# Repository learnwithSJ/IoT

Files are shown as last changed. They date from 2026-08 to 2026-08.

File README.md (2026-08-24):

# Smart AI Plug

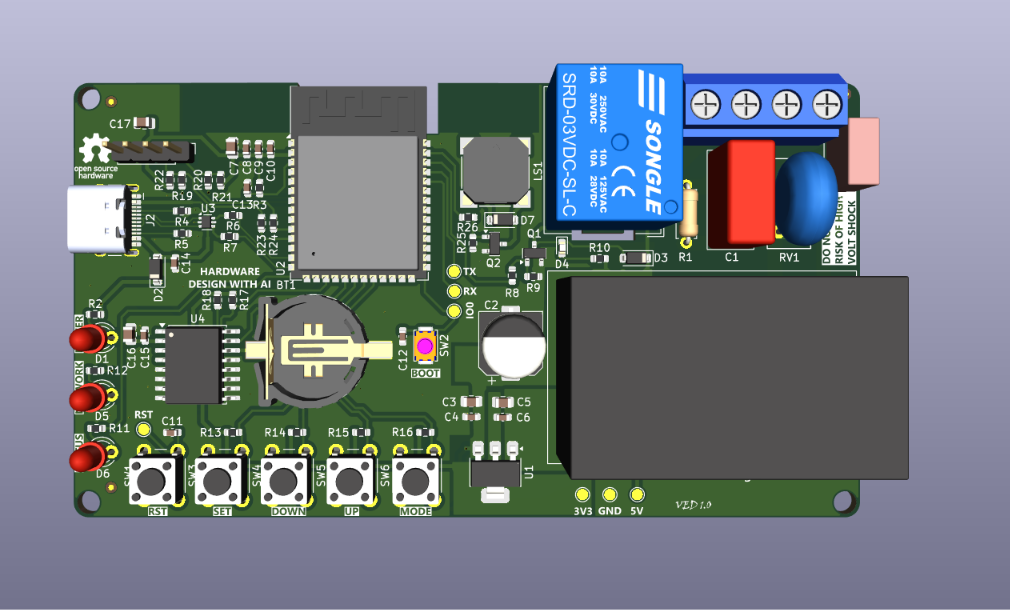
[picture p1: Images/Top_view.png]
Top-img


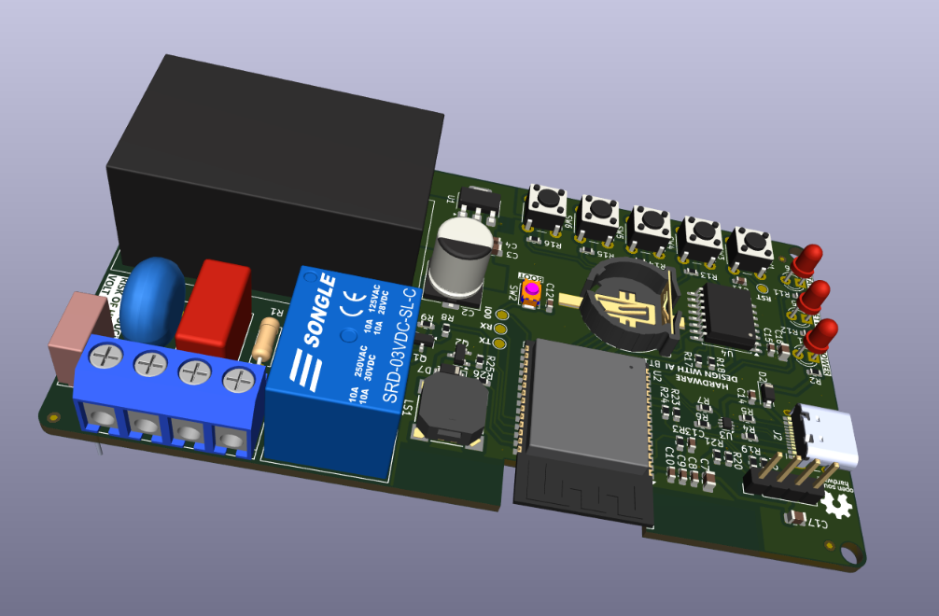
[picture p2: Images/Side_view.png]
Side-img


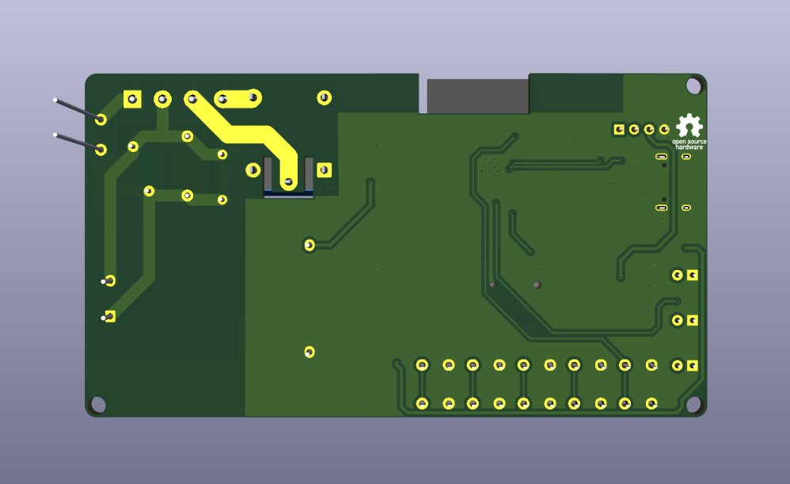
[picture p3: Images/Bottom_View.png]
Bot-img


An ESP32-S3 based IoT smart plug designed for remote and scheduled control of electrical appliances.

> **Project Status:** PCB Design Completed — Hardware Assembly and Testing Not Yet Performed.

## Overview

Smart AI Plug is a smart plug concept designed around the ESP32-S3 microcontroller. The system is intended to provide wireless appliance control along with scheduled operation.

The complete circuit and PCB were designed using **KiCad**.

## Features

* ESP32-S3 based design
* Single-channel relay control (SPDT)
* Wi-Fi and Bluetooth connectivity
* Relay-based appliance switching
* RTC-based scheduled operation
* USB-C interface
* Onboard RTC with battery backup (DS3231M + CH291-1220LF)
* Status LEDs - Network, Error, General indication
* Buzzer feedback (MLT-8530)
* 4x tactile switches for local control
* AC-DC power supply section
* PCB protection circuitry
* Compact PCB design

## 🏗️ System Architecture

```
220V AC Input
     │
     ▼
[F1 Fuse 500mA] ──→ [MOV RV1 Surge Protection]
     │
     ▼
[HLK-5M05] ──→ 5V DC
     │
     ├──→ [Relay K1 SPDT] ──→ Load Output (Screw Terminal J2)
     │
     └──→ [AMS1117-3.3] ──→ 3.3V DC
               │
               ├──→ [ESP32-S3-WROOM-1] ←→ WiFi / BLE
               ├──→ [DS3231M RTC] (I2C)
               ├──→ [Status LEDs]
               ├──→ [Buzzer MLT-8530]
               ├──→ [Tactile Switches x4]
               └──→ [USB-C] ──→ Firmware Flash / Serial Debug
```

---

## 🔧 Hardware Specifications

| Parameter | Details |
|---|---|
| Microcontroller | ESP32-S3-WROOM-1 |
| Input Voltage | 220V AC |
| Operating Voltage | 5V DC / 3.3V DC |
| Power Supply Module | HLK-5M05 (220VAC → 5VDC) |
| LDO Regulator | AMS1117-3.3 |
| Relay | SPDT — 1 Channel |
| RTC | DS3231M (I2C) |
| RTC Battery | CH291-1220LF (Coin Cell) |
| USB Connector | USB-C (USB 2.0) |
| ESD Protection | USBLC6-2P6 |
| Surge Protection | MOV 10D561K |
| Fuse | 500mA / 250V |
| Status LEDs | Red, Blue, Green |
| Buzzer | MLT-8530 |
| Switches | 4x Tactile + 1x Boot + 1x Reset |
| PCB Tool | KiCad 9.0.1 |
| Board Revision | Rev-v0.1.0A |

---

## PCB Design

The schematic and PCB layout were designed using **KiCad**.

## Repository Structure

```text
KiCad/          → KiCad schematic, PCB and project files
Documentation/  → Design documents and diagrams
Images/         → Project images
BOM/            → Bill of Materials
Firmware/       → Firmware documentation
```

## Project Status

The schematic and PCB layout have been completed in KiCad.

The current version is a **design/prototype-stage project**. Physical PCB fabrication, assembly, firmware deployment, and hardware testing have not yet been completed.

## Future Improvements

* Fabricate and assemble the PCB
* Develop and test ESP32-S3 firmware
* Add cloud-based appliance control
* Integrate voice assistant support
* Perform electrical safety and functional testing
* Optimize PCB size and power consumption

## 🏭 Manufacturing

Fabrication files are located in `Hardware/3-Manufacturing-Files/` and include:

- **Gerber files** - for PCB fabrication
- **BOM (Bill of Materials)** - component list with values and part numbers
- **CPL (Component Placement List)** - for SMT assembly

## Designed By

**Shubhank**

## Acknowledgements

Special thanks to **Ampnics** for creating and sharing the original Zeen AI Plug project and providing the YouTube tutorial and open-source resources that helped me understand and recreate this project.

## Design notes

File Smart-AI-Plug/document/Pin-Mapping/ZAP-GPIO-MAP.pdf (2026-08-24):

Zeen-AI-Plug | GPIO Mapping
Device | GPIO | PIN | Type | Comment
3.3V | -- | 2 | PWR
GND | -- | 1/40 | PWR
VBUS | -- | -- | PWR
USB_D+ | IO20 | 14 | PROGRAM/DEBUG
USB_D- | IO19 | 13 | PROGRAM/DEBUG
SW1 | EN | 3 | IN
SW2 | IO0 | 27 | IN
SW3 | IO11 | 19 | IN
SW4 | IO12 | 20 | IN
SW5 | IO13 | 21 | IN
SW6 | IO14 | 22 | IN
RTC_sda | IO8 | 12 | COMM
RTC_scl | IO9 | 17 | COMM
DIS_sda | IO8 | 12 | COMM/OP
DIS_scl | IO9 | 17 | COMM/OP
OPT_dis_sda | IO17 | 10 | COMM/OP
OPT_dis_scl | IO18 | 11 | CPMM/OP
Relay | IO2 | 38 | OP
Network-LED | IO4 | 4 | OP
Status-LED | IO3 | 15 | OP
Buzzer | IO1 | 39 | OP

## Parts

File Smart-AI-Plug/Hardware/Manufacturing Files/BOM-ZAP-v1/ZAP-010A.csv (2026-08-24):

Reference | Qty | Value | DNP | Exclude from BOM | Exclude from Board | Footprint | Datasheet
BT1 | 1 | CH291-1220LF |  |  |  | CH291-1220LF:BAT_CH291-1220LF
C1 | 1 | 0.1uF |  |  |  | Capacitor_THT:C_Rect_L13.0mm_W6.0mm_P10.00mm_FKS3_FKP3_MKS4 | ~
C2 | 1 | 220uF |  |  |  | Capacitor_SMD:CP_Elec_8x10 | ~
C3,C5,C7 | 3 | 10uF |  |  |  | Capacitor_SMD:C_0805_2012Metric | ~
C4,C6,C8,C9,C10,C11,C12,C13,C14,C15 | 10 | 0.1uF |  |  |  | Capacitor_SMD:C_0603_1608Metric | ~
C16 | 1 | 2.2uF |  |  |  | Capacitor_SMD:C_0805_2012Metric | ~
C17 | 1 | 0.1uF |  |  |  | Capacitor_SMD:C_0805_2012Metric | ~
D1,D5,D6 | 3 | RED |  |  |  | LED_THT:LED_D3.0mm | ~
D2 | 1 | MBR0520 |  |  |  | Diode_SMD:D_SOD-123 | http://www.mccsemi.com/up_pdf/MBR0520~MBR0580(SOD123).pdf
D3,D7 | 2 | 1N4148W |  |  |  | Diode_SMD:D_SOD-123 | https://www.vishay.com/docs/85748/1n4148w.pdf
D4 | 1 | RED |  |  |  | LED_SMD:LED_0603_1608Metric | ~
F1 | 1 | 500mA 250V |  |  |  | Fuse:Fuse_Littelfuse_395Series | ~
FID1,FID2,FID3 | 3 | Fiducial |  | Excluded from BOM |  | Fiducial:Fiducial_0.75mm_Mask1.5mm | ~
J1 | 1 | Screw_Terminal_01x04 |  |  |  | TerminalBlock:TerminalBlock_bornier-4_P5.08mm | ~
J2 | 1 | USB_C_Receptacle_USB2.0_16P |  |  |  | Connector_USB:USB_C_Receptacle_HCTL_HC-TYPE-C-16P-01A | https://www.usb.org/sites/default/files/documents/usb_type-c.zip
J3 | 1 | Conn_01x04_Pin |  |  |  | Connector_PinHeader_2.54mm:PinHeader_1x04_P2.54mm_Vertical | ~
K1 | 1 | Relay_SPDT |  |  |  | Relay_THT:Relay_SPDT_Hongfa_HF3F-L-xx-1ZL1T | ~
LS1 | 1 | MLT-8530 |  |  |  | ul_MLT-8530:MLT-8530_JHE
PS1 | 1 | HLK-5M05 |  |  |  | Converter_ACDC:Converter_ACDC_Hi-Link_HLK-5Mxx | http://h.hlktech.com/download/ACDC%E7%94%B5%E6%BA%90%E6%A8%A1%E5%9D%975W%E7%B3%BB%E5%88%97/1/%E6%B5%B7%E5%87%8C%E7%A7%915W%E7%B3%BB%E5%88%97%E7%94%B5%E6%BA%90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
Q1,Q2 | 2 | AO3400A |  |  |  | Package_TO_SOT_SMD:SOT-23 | http://www.aosmd.com/pdfs/datasheet/AO3400A.pdf
R1 | 1 | 1M |  |  |  | Resistor_THT:R_Axial_DIN0207_L6.3mm_D2.5mm_P7.62mm_Horizontal | ~
R2 | 1 | 4K7 |  |  |  | Resistor_SMD:R_0603_1608Metric | ~
R3,R9,R13,R14,R15,R16,R17,R18,R21,R22,R25 | 11 | 10K |  |  |  | Resistor_SMD:R_0603_1608Metric | ~
R4,R5 | 2 | 5K1 |  |  |  | Resistor_SMD:R_0603_1608Metric | ~
R6,R7,R19,R20,R23,R24 | 6 | 0R |  |  |  | Resistor_SMD:R_0603_1608Metric | ~
R8,R10,R11,R12,R26 | 5 | 1K |  |  |  | Resistor_SMD:R_0603_1608Metric | ~
RV1 | 1 | 10D56K |  |  |  | Varistor:RV_Disc_D12mm_W5.8mm_P7.5mm | ~
SW1,SW3,SW4,SW5,SW6 | 5 | SW_Push |  |  |  | Button_Switch_THT:SW_PUSH_6mm | ~
SW2 | 1 | SW_Push |  |  |  | Button_Switch_SMD:SW_Push_SPST_NO_Alps_SKRK | ~
TP1 | 1 | TXD0 |  |  |  | TestPoint:TestPoint_Pad_D1.5mm | ~
TP2 | 1 | RXD0 |  |  |  | TestPoint:TestPoint_Pad_D1.5mm | ~
TP3 | 1 | 3V3 |  |  |  | TestPoint:TestPoint_Pad_D1.5mm | ~
TP4 | 1 | 5V |  |  |  | TestPoint:TestPoint_Pad_D1.5mm | ~
TP5 | 1 | EN |  |  |  | TestPoint:TestPoint_Pad_D1.5mm | ~
TP6 | 1 | BOOT |  |  |  | TestPoint:TestPoint_Pad_D1.5mm | ~
TP7 | 1 | GND |  |  |  | TestPoint:TestPoint_Pad_D1.5mm | ~
U1 | 1 | AMS1117-3.3 |  |  |  | Package_TO_SOT_SMD:SOT-223-3_TabPin2 | http://www.advanced-monolithic.com/pdf/ds1117.pdf
U2 | 1 | ESP32-S3-WROOM-1 |  |  |  | RF_Module:ESP32-S3-WROOM-1 | https://www.espressif.com/sites/default/files/documentation/esp32-s3-wroom-1_wroom-1u_datasheet_en.pdf
U3 | 1 | USBLC6-2P6 |  |  |  | Package_TO_SOT_SMD:SOT-666 | https://www.st.com/resource/en/datasheet/usblc6-2.pdf
U4 | 1 | DS3231M |  |  |  | Package_SO:SOIC-16W_7.5x10.3mm_P1.27mm | http://datasheets.maximintegrated.com/en/ds/DS3231.pdf

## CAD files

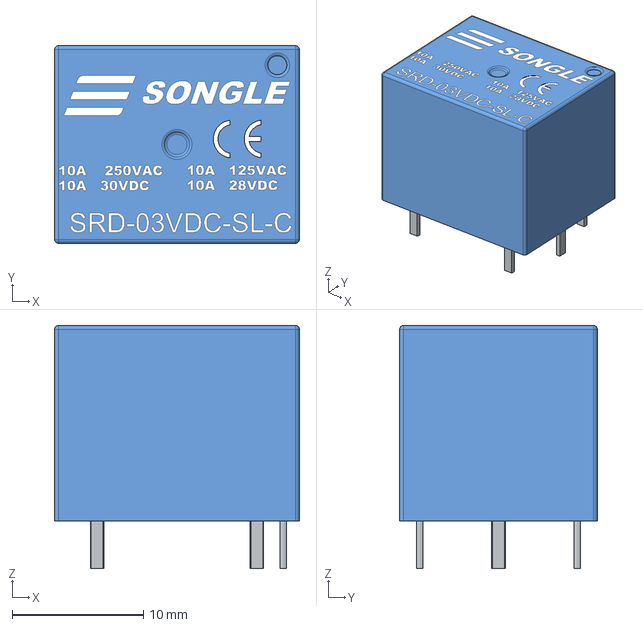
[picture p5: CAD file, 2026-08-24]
Smart-AI-Plug/Hardware/External-3D-Modules/Relay - SRD-03VDC-SL-C.stp
18.7 x 15.1 x 18.6 mm

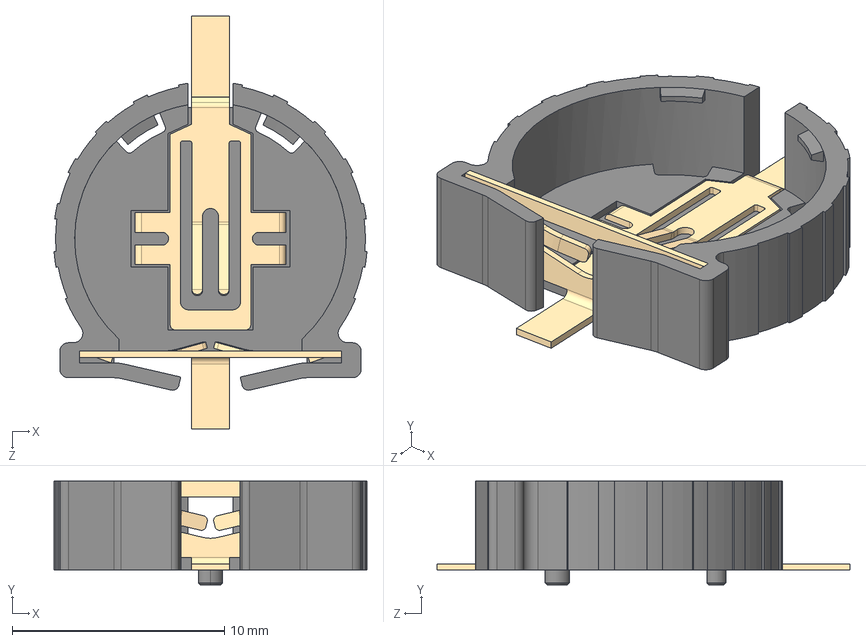
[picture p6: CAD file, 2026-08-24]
Smart-AI-Plug/Hardware/External-libraries/CH291-1220LF/CH291-1220LF.step
14.7 x 4.90 x 19.4 mm

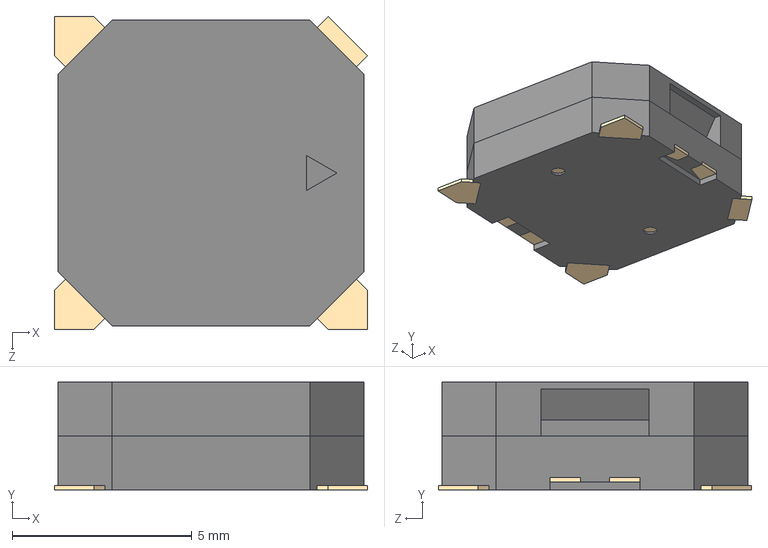
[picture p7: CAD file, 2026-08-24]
Smart-AI-Plug/Hardware/External-3D-Modules/MLT-8530--3DModel-STEP-269445.STEP
8.70 x 3.00 x 8.70 mm

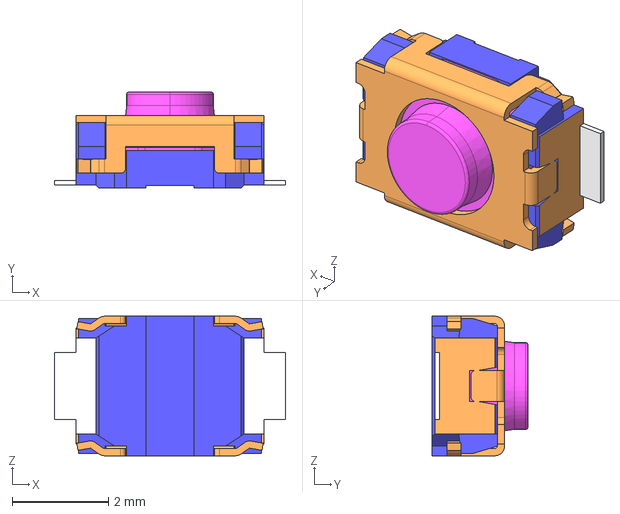
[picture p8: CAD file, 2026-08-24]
Smart-AI-Plug/Hardware/External-3D-Modules/skrkaee010.stp
4.80 x 2.00 x 2.90 mm

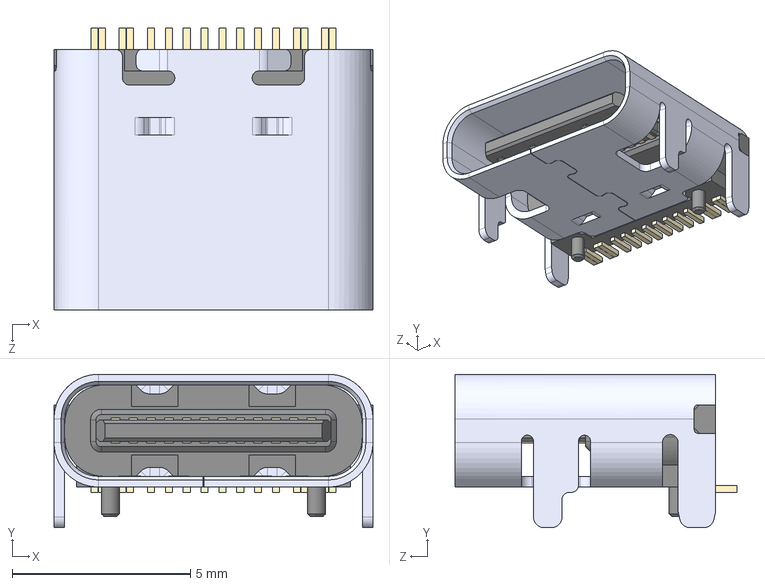
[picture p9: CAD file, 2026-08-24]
Smart-AI-Plug/Hardware/External-3D-Modules/TYPE-C-31-M-12--3DModel-STEP-56544.STEP
8.94 x 4.30 x 7.90 mm

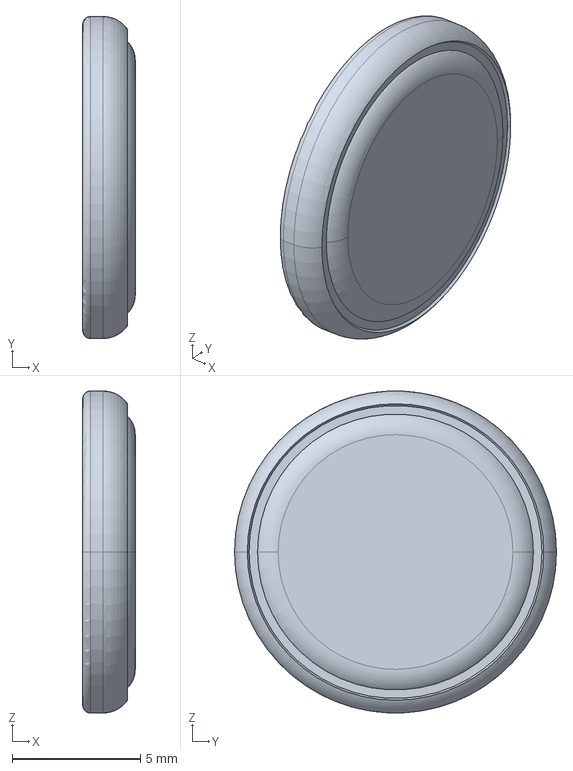
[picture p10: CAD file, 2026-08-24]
Smart-AI-Plug/Hardware/External-3D-Modules/k_cr1220_lithium-cell.stp
2.05 x 12.6 x 12.5 mm

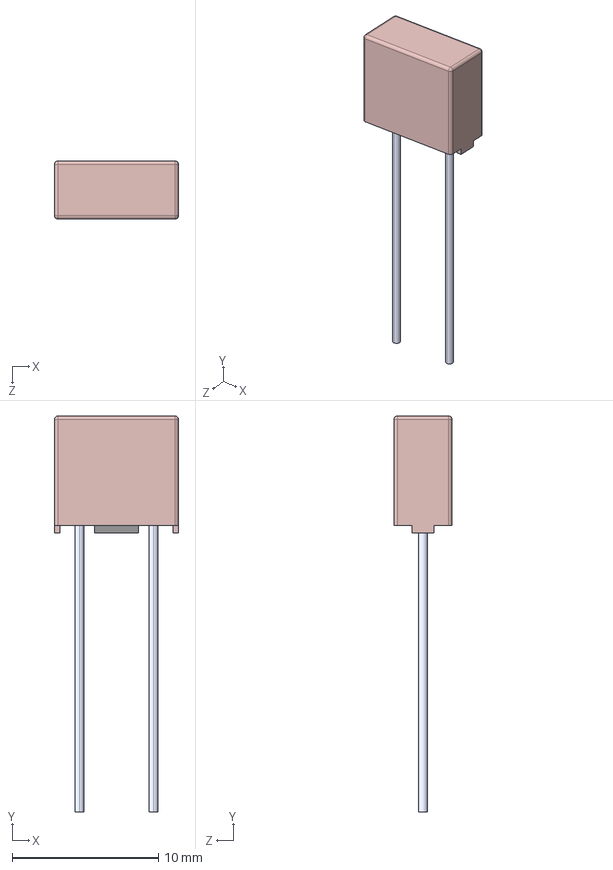
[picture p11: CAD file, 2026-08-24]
Smart-AI-Plug/Hardware/External-3D-Modules/39208000000.STEP
8.50 x 27.1 x 4.00 mm

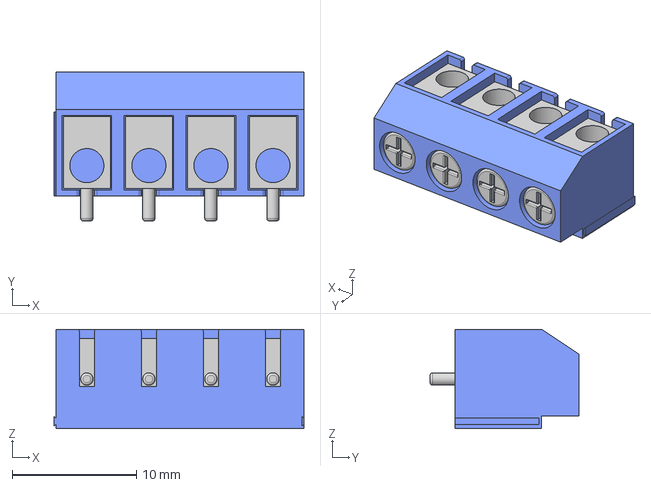
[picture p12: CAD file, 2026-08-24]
Smart-AI-Plug/Hardware/External-3D-Modules/Screw Terminal Block 5mm Blue 4-way.step
20.1 x 12.0 x 8.00 mm

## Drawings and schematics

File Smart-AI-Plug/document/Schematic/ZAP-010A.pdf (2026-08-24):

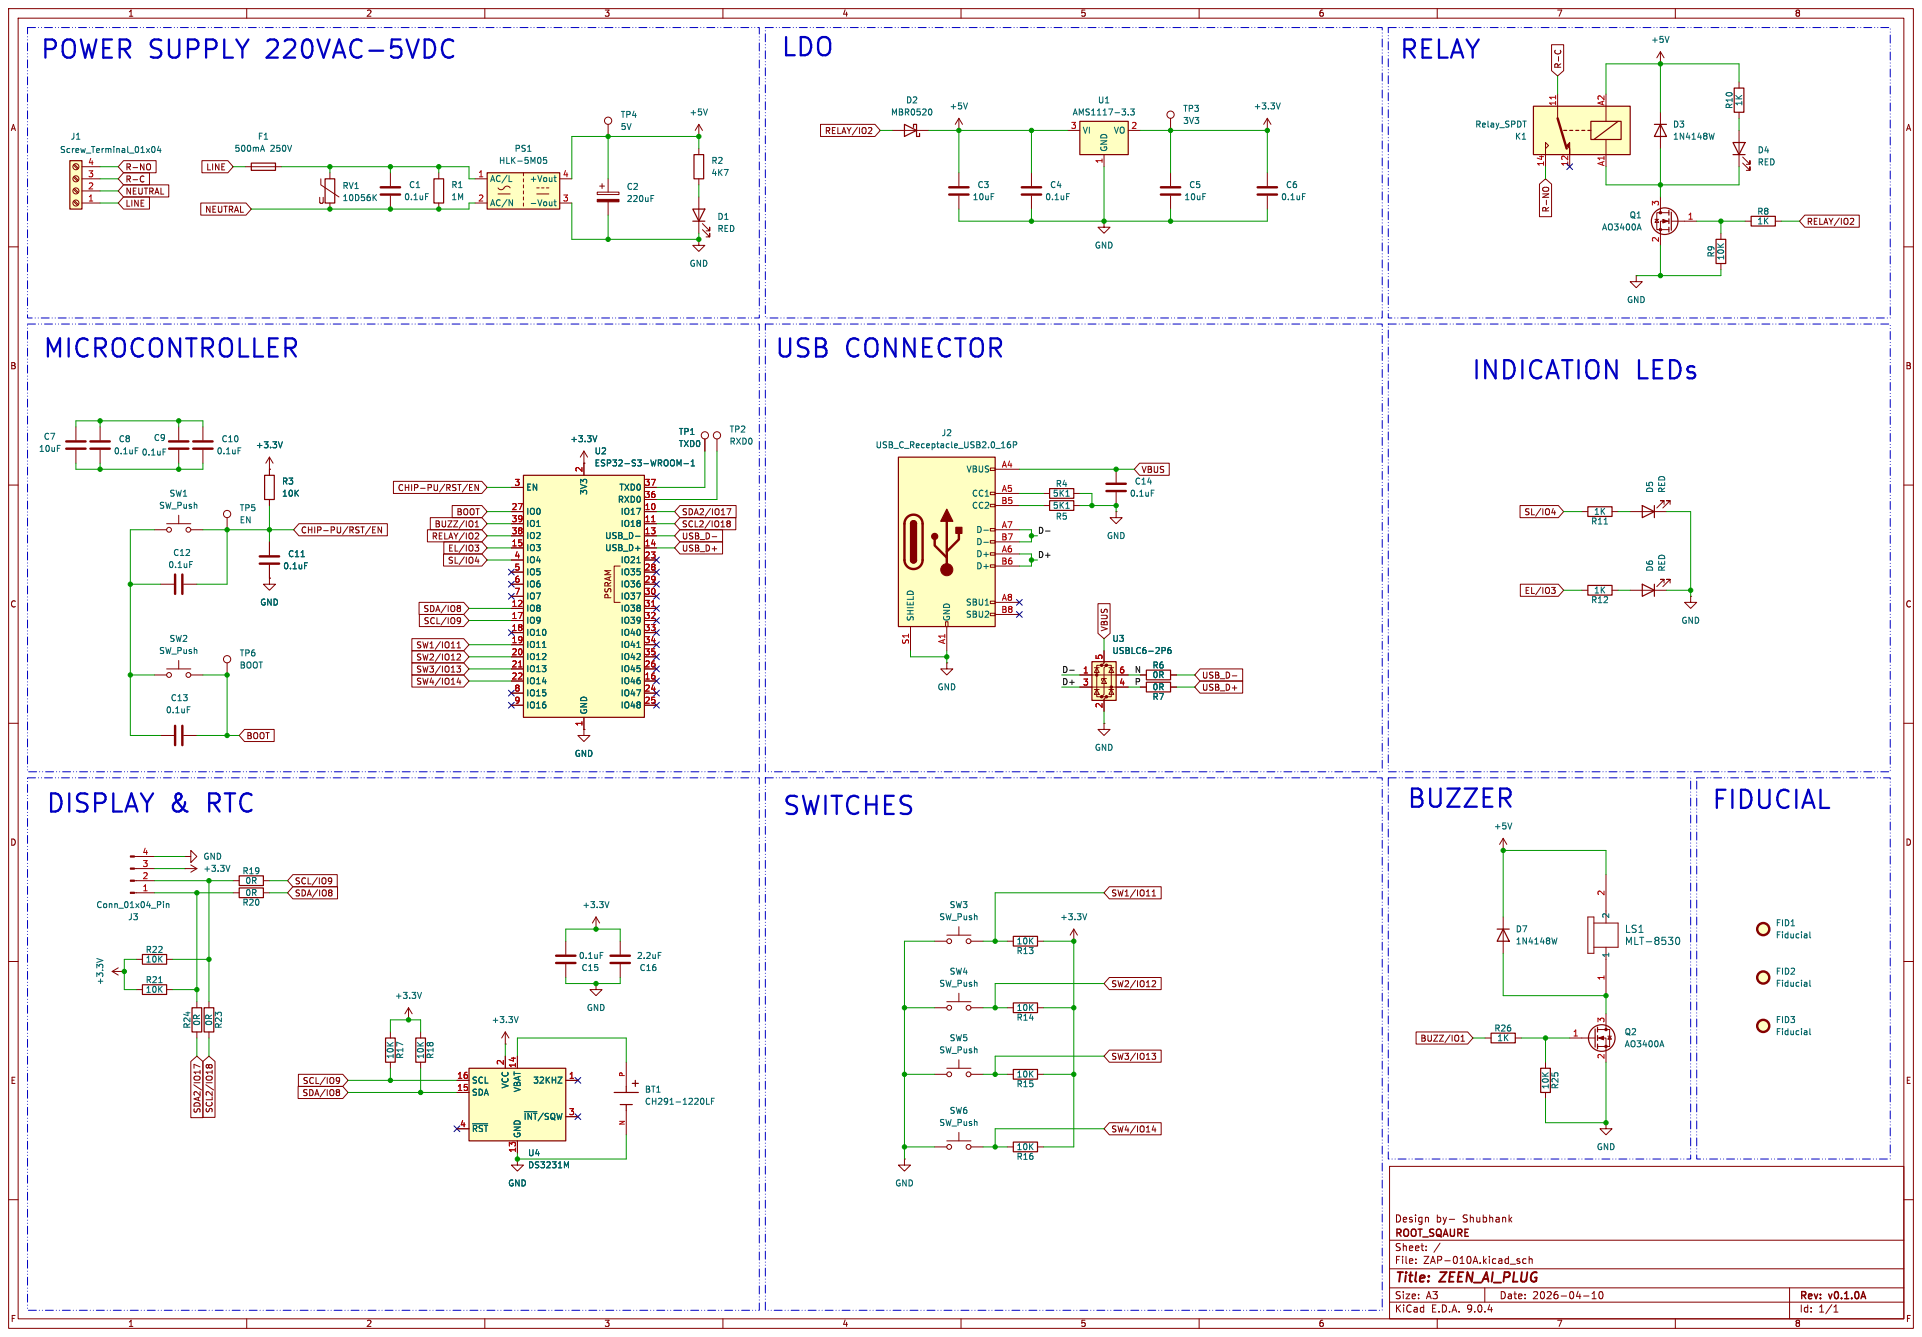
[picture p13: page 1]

CHIP-PU/RST/EN

Design by- Shubhank GND

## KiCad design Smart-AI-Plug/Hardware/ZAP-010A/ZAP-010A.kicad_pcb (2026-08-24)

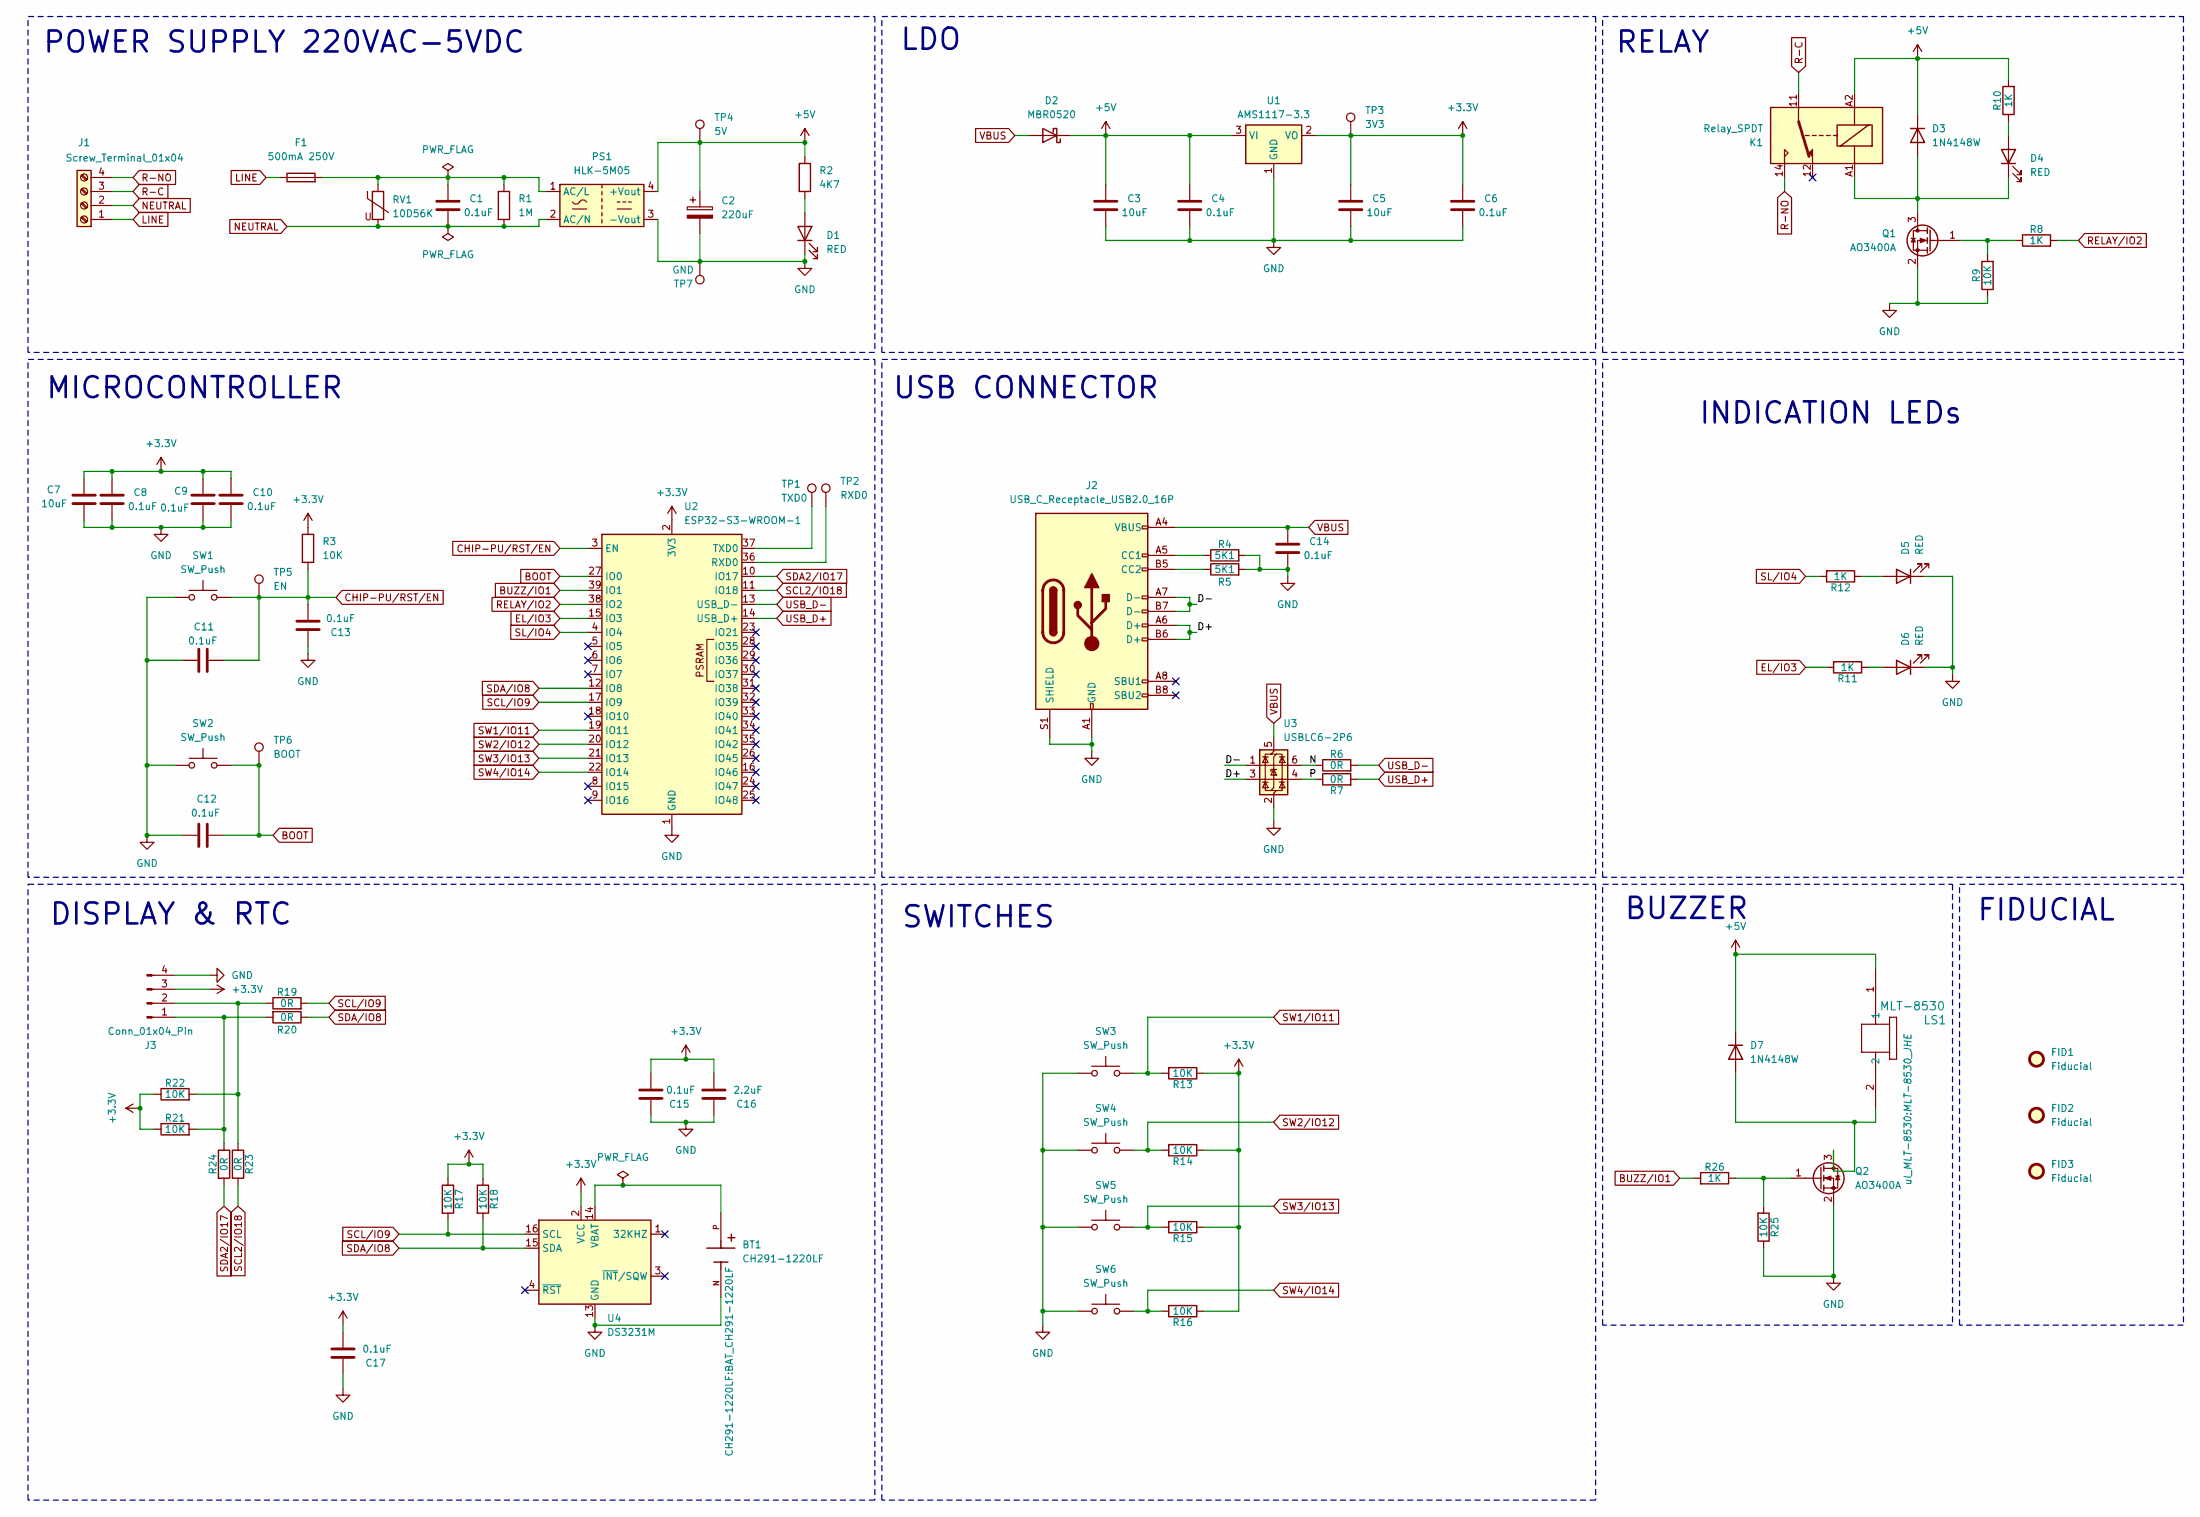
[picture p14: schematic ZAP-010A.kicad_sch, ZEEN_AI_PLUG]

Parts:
BT1: CH291-1220LF; BAT_CH291-1220LF; PARTREV A
C1: 0.1uF; C_Rect_L13.0mm_W6.0mm_P10.00mm_FKS3_FKP3_MKS4
C2: 220uF; CP_Elec_8x10
C3, C5, C7: 10uF; C_0805_2012Metric
C4, C6, C8, C9, C10, C11, C12, C13, C14, C15: 0.1uF; C_0603_1608Metric
C16: 2.2uF; C_0805_2012Metric
C17: 0.1uF; C_0805_2012Metric
D1, D5, D6: RED; LED_D3.0mm
D2: MBR0520; D_SOD-123
D3, D7: 1N4148W; D_SOD-123
D4: RED; LED_0603_1608Metric
F1: 500mA 250V; Fuse_Littelfuse_395Series
FID1, FID2, FID3: Fiducial; Fiducial_0.75mm_Mask1.5mm
J1: Screw_Terminal_01x04; TerminalBlock_bornier-4_P5.08mm
J2: USB_C_Receptacle_USB2.0_16P; USB_C_Receptacle_HCTL_HC-TYPE-C-16P-01A
J3: Conn_01x04_Pin; PinHeader_1x04_P2.54mm_Vertical
K1: Relay_SPDT; Relay_SPDT_Hongfa_HF3F-L-xx-1ZL1T
LS1: MLT-8530; MLT-8530_JHE
PS1: HLK-5M05; Converter_ACDC_Hi-Link_HLK-5Mxx
Q1, Q2: AO3400A; SOT-23
R1: 1M; R_Axial_DIN0207_L6.3mm_D2.5mm_P7.62mm_Horizontal
R2: 4K7; R_0603_1608Metric
R3, R9, R13, R14, R15, R16, R17, R18, R21, R22, R25: 10K; R_0603_1608Metric
R4, R5: 5K1; R_0603_1608Metric
R6, R7, R19, R20, R23, R24: 0R; R_0603_1608Metric
R8, R10, R11, R12, R26: 1K; R_0603_1608Metric
RV1: 10D56K; RV_Disc_D12mm_W5.8mm_P7.5mm
SW1, SW3, SW4, SW5, SW6: SW_Push; SW_PUSH_6mm
SW2: SW_Push; SW_Push_SPST_NO_Alps_SKRK
TP1: TXD0; TestPoint_Pad_D1.5mm
TP2: RXD0; TestPoint_Pad_D1.5mm
TP3: 3V3; TestPoint_Pad_D1.5mm
TP4: 5V; TestPoint_Pad_D1.5mm
TP5: EN; TestPoint_Pad_D1.5mm
TP6: BOOT; TestPoint_Pad_D1.5mm
TP7: GND; TestPoint_Pad_D1.5mm
U1: AMS1117-3.3; SOT-223-3_TabPin2
U2: ESP32-S3-WROOM-1
U3: USBLC6-2P6; SOT-666
U4: DS3231M; SOIC-16W_7.5x10.3mm_P1.27mm

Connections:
+3.3V: C5.1, C6.1, C7.1, C8.1, C9.1, C10.1, C15.1, C16.1, C17.1, J3.3, R3.1, R13.1, R14.1, R15.1, R16.1, R17.1, R18.1, R21.1, R22.1, TP3.1, U1.2 (VO), U2.2 (3V3), U4.2 (VCC)
+5V: C2.1, C3.1, C4.1, D2.1 (K), D3.1 (K), D7.1 (K), K1.A2, LS1.1, PS1.4 (+Vout), R2.1, R10.2, TP4.1, U1.3 (VI)
/D+: J2.A6 (D+), J2.B6 (D+), U3.3 (I/O2)
/D-: J2.A7 (D-), J2.B7 (D-), U3.1 (I/O1)
/N: R6.1, U3.6 (I/O1)
/P: R7.1, U3.4 (I/O2)
BOOT: C12.1, SW2.2, TP6.1, U2.27 (IO0)
BUZZ/IO1: R26.2, U2.39 (IO1)
CHIP-PU/RST/EN: C11.1, C13.2, R3.2, SW1.2, TP5.1, U2.3 (EN)
EL/IO3: R11.2, U2.15 (IO3)
GND: BT1.N, C2.2, C3.2, C4.2, C5.2, C6.2, C7.2, C8.2, C9.2, C10.2, C11.2, C12.2, C13.1, C14.2, C15.2, C16.2, C17.2, D1.1 (K), D5.1 (K), D6.1 (K), J2.A1 (GND), J2.A12 (GND), J2.B1 (GND), J2.B12 (GND), J2.S1 (SHIELD), J3.4, PS1.3 (-Vout), Q1.2 (S), Q2.2 (S), R4.2, R5.2, R9.1, R25.1, SW1.1, SW2.1, SW3.1, SW4.1, SW5.1, SW6.1, TP7.1, U1.1 (GND), U2.1 (GND), U2.40 (GND), U2.41 (GND), U3.2 (GND), U4.5 (GND), U4.6 (GND), U4.7 (GND), U4.8 (GND), U4.9 (GND), U4.10 (GND), U4.11 (GND), U4.12 (GND), U4.13 (GND)
LINE: F1.1, J1.1
NEUTRAL: C1.2, J1.2, PS1.2 (AC/N), R1.2, RV1.2
unnamed: D1.2 (A), R2.2
unnamed: D3.2 (A), D4.1 (K), K1.A1, Q1.3 (D)
unnamed: D4.2 (A), R10.1
unnamed: D5.2 (A), R12.1
unnamed: D6.2 (A), R11.1
unnamed: D7.2 (A), LS1.2, Q2.3 (D)
unnamed: J2.A5 (CC1), R4.1
unnamed: J2.B5 (CC2), R5.1
unnamed: J3.1, R20.2, R21.2, R24.1
unnamed: J3.2, R19.1, R22.2, R23.1
unnamed: C1.1, F1.2, PS1.1 (AC/L), R1.1, RV1.1
unnamed: Q1.1 (G), R8.1, R9.2
unnamed: Q2.1 (G), R25.2, R26.1
unnamed: TP2.1, U2.36 (RXD0)
unnamed: TP1.1, U2.37 (TXD0)
unnamed: BT1.P, U4.14 (VBAT)
R-C: J1.3, K1.11
R-NO: J1.4, K1.14
RELAY/IO2: R8.2, U2.38 (IO2)
SCL2/IO18: R23.2, U2.11 (IO18)
SCL/IO9: R17.2, R19.2, U2.17 (IO9), U4.16 (SCL)
SDA2/IO17: R24.2, U2.10 (IO17)
SDA/IO8: R18.2, R20.1, U2.12 (IO8), U4.15 (SDA)
SL/IO4: R12.2, U2.4 (IO4)
SW1/IO11: R13.2, SW3.2, U2.19 (IO11)
SW2/IO12: R14.2, SW4.2, U2.20 (IO12)
SW3/IO13: R15.2, SW5.2, U2.21 (IO13)
SW4/IO14: R16.2, SW6.2, U2.22 (IO14)
USB_D+: R7.2, U2.14 (USB_D+)
USB_D-: R6.2, U2.13 (USB_D-)
VBUS: C14.1, D2.2 (A), J2.A4 (VBUS), J2.A9 (VBUS), J2.B4 (VBUS), J2.B9 (VBUS), U3.5 (VBUS)

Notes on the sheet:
DISPLAY & RTC
LDO
BUZZER
POWER SUPPLY 220VAC-5VDC
INDICATION LEDs
MICROCONTROLLER
RELAY
USB CONNECTOR
SWITCHES
FIDUCIAL

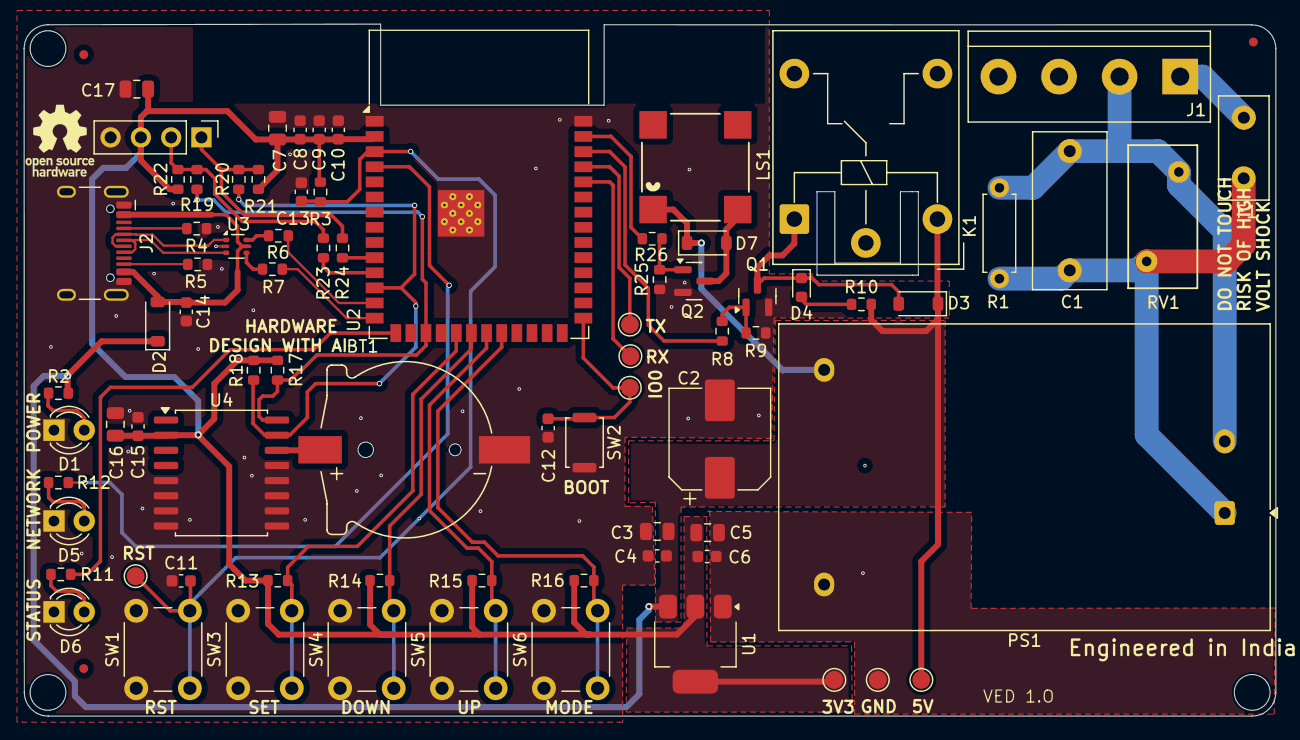
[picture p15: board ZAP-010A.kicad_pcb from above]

Board: 2 copper layers, 105.0 x 58.0 mm, 81 parts (0 on the bottom side), 44 nets.

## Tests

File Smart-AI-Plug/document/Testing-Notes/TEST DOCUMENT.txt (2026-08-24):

TEST DOCUMENT 

Zeen-AI-Plug, v0.1.0A|Nov 2025

Test Points
TP1: MCU RESET/EN 
TP2: MCU BOOT
TP3: 5VDC
TP4: GND
TP5: TXD0
TP6: RXD0
TP7: 3.3VDC
